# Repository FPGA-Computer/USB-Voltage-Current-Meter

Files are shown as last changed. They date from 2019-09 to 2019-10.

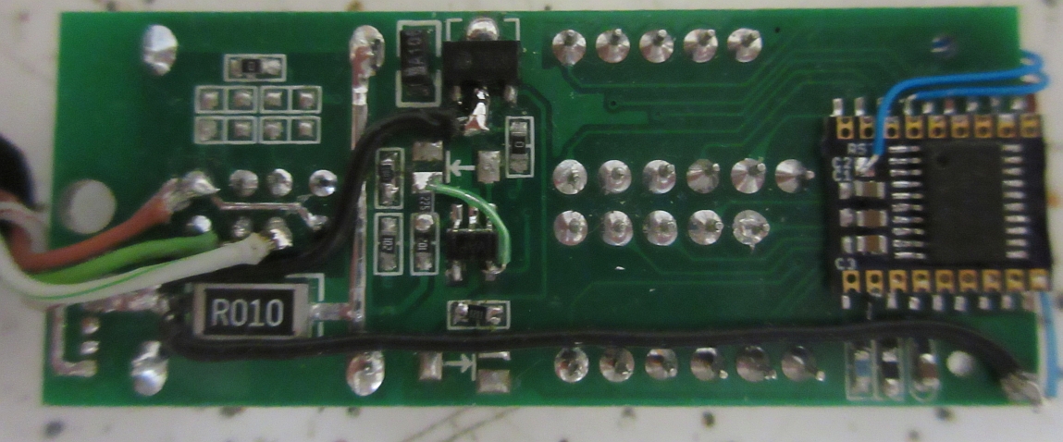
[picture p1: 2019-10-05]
hardware/uC Mod - PCB.JPG

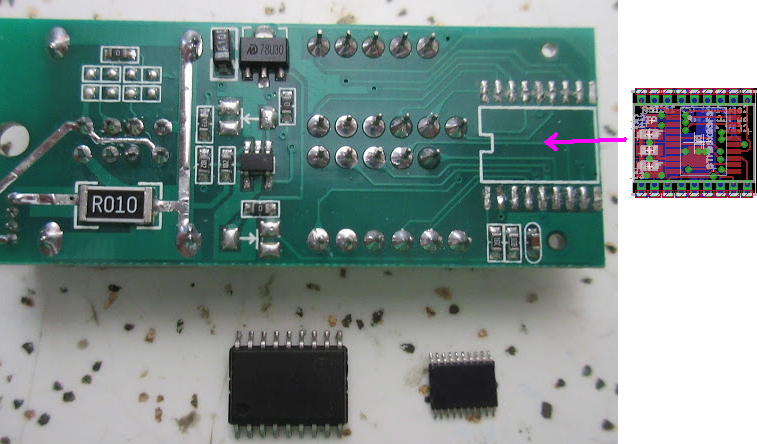
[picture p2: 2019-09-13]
hardware/PCB.png

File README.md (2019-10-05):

USB Meter
=========

This is the repository for my KW203 USB meter mod.
This mod is provided as is. This is a mod, so no full schematics.

The KW203 USB meter like most of those in the price range have very lousy
resolution and cannot read low currents.  This mod is replacing the
unknown microcontroller with a STM8S003F3 and a few modification to 
improve on the resolution and accuracy. The modifications and the 
calibration is what makes this a usable test equipment.

This is a hack that depends on the existing questionable components i.e. 
3V LDO (+/-3%) and current sensing resistor (??? %). 

Each unit has to be calibrated against a multimeter with a linear 
regression for reasonable accuracy. The current measurement suffers
from non-linearity at high current due to heating effects on the sense 
resistor and the bad layout traces. Trimppot won't help here.  To manage 
the errors, I use a piecewise linear fit. 

Firmware is written for Cosmic C which ST arranged to have for free use 
with their STM8 chips.

Project page: mod, documentations, photos

https://hw-by-design.blogspot.com/2019/08/usb-meter-modding.html

https://hw-by-design.blogspot.com/2019/09/usb-meter-modding-part-2.html

https://hw-by-design.blogspot.com/2019/10/uc-mod-pcb-part-3.html

Licensing:

Schematic/PCB: Creative Commons 4.0 Attribution-ShareAlike 4.0 International

Firmware: source code: GPL v3

Updates:

New PCB for the adapter board - verified.

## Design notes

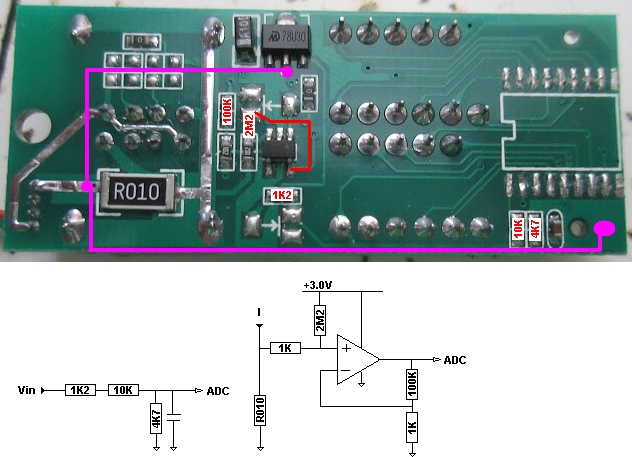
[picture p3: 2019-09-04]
hardware/Analog mod.jpg

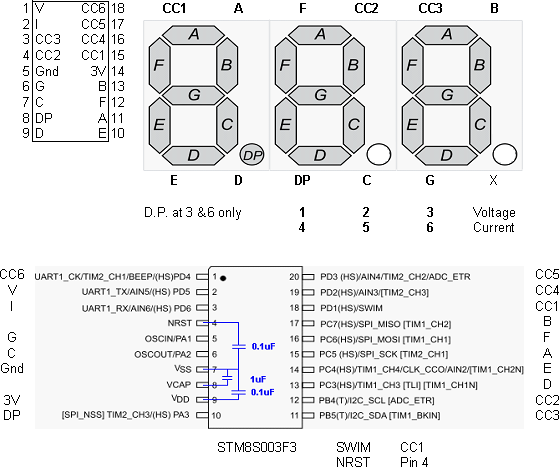
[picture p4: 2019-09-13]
hardware/uC pins mapping.png

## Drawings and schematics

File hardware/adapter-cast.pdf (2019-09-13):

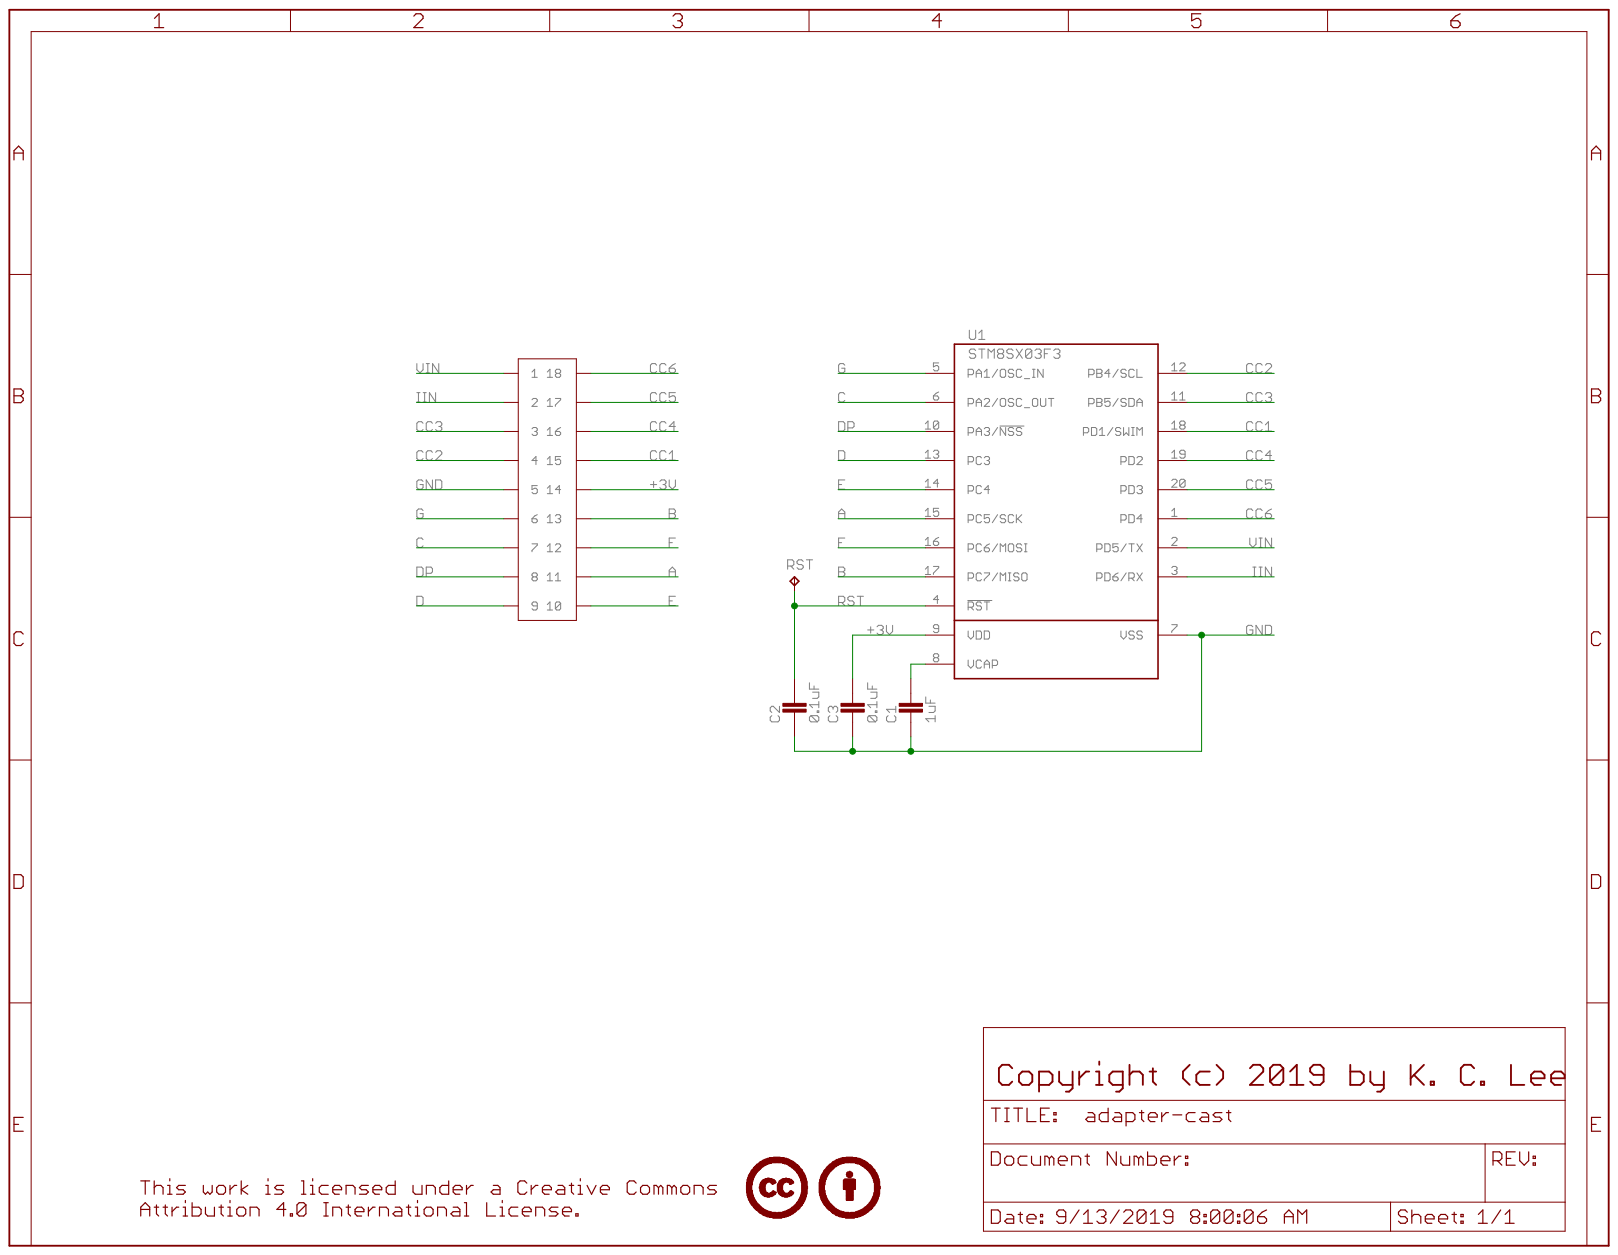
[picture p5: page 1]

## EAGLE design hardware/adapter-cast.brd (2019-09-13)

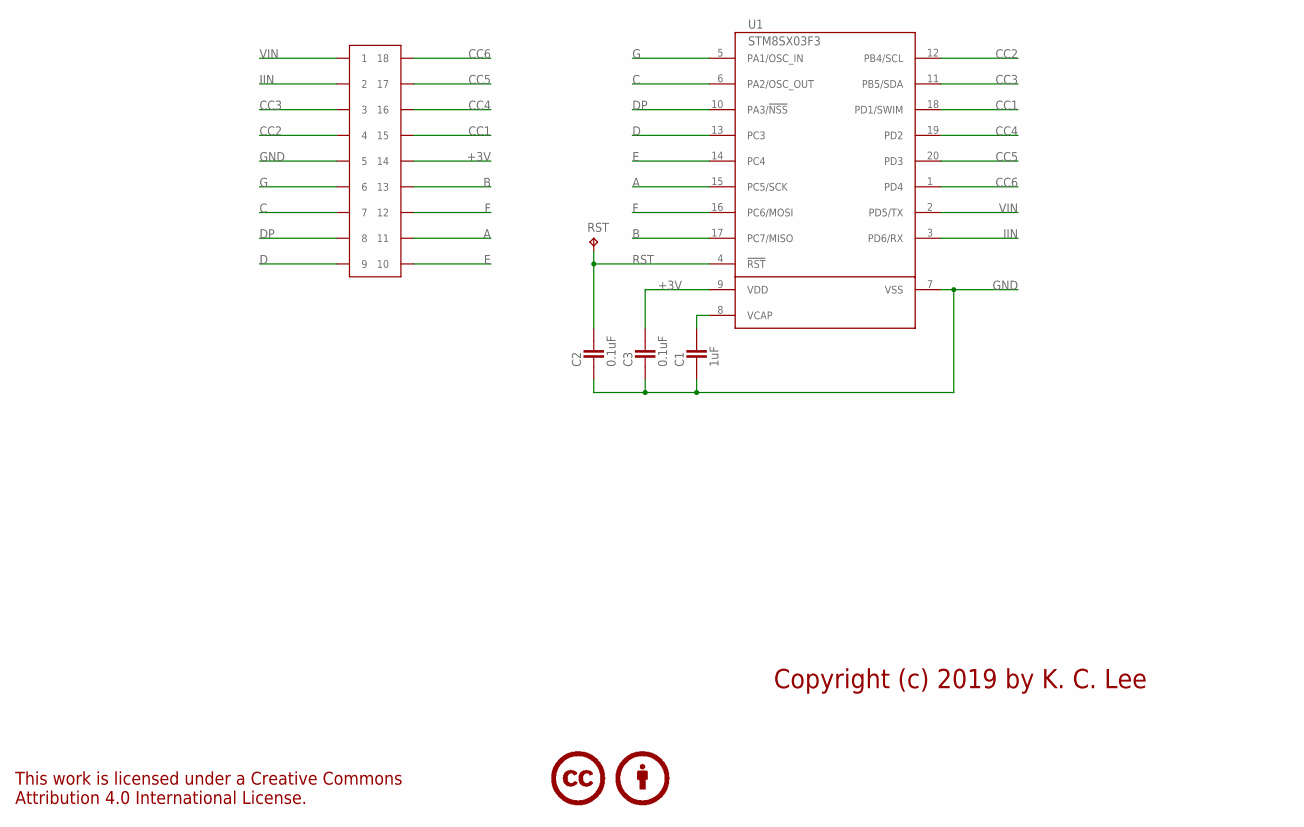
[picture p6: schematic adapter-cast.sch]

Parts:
C1: 1uF; CAPC1608X92N
C2, C3: 0.1uF; CAPC1608X92N
LICENSE1: CC-BYNONE; CC-NONE
P1: DUMMY-SO18WCAST; SO18W-CAST
RST: TP; TP11SQ
U1: STM8SX03F3; TSSOP20

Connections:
+3V: C3.2, P1.P$14 (14), U1.9 (VDD)
A: P1.P$11 (11), U1.15 (PC5/SCK)
B: P1.P$13 (13), U1.17 (PC7/MISO)
C: P1.P$7 (7), U1.6 (PA2/OSC_OUT)
CC1: P1.P$15 (15), U1.18 (PD1/SWIM)
CC2: P1.P$4 (4), U1.12 (PB4/SCL)
CC3: P1.P$3 (3), U1.11 (PB5/SDA)
CC4: P1.P$16 (16), U1.19 (PD2)
CC5: P1.P$17 (17), U1.20 (PD3)
CC6: P1.P$18 (18), U1.1 (PD4)
D: P1.P$9 (9), U1.13 (PC3)
DP: P1.P$8 (8), U1.10 (PA3/!NSS)
E: P1.P$10 (10), U1.14 (PC4)
F: P1.P$12 (12), U1.16 (PC6/MOSI)
G: P1.P$6 (6), U1.5 (PA1/OSC_IN)
GND: C1.1, C2.1, C3.1, P1.P$5 (5), U1.7 (VSS)
IIN: P1.P$2 (2), U1.3 (PD6/RX)
unnamed: C1.2, U1.8 (VCAP)
RST: C2.2, RST.TP, U1.4 (!RST)
VIN: P1.P$1 (1), U1.2 (PD5/TX)

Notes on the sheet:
Copyright (c) 2019 by K. C. Lee

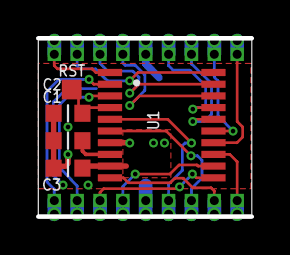
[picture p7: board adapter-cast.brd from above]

Board: 2 copper layers, 11.9 x 9.9 mm, 7 parts (0 on the bottom side), 20 nets.

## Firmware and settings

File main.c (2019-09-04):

/*
 * main.c
 *
 * Created: August 30, 2019, 6:07:55 PM
 *  Author: K. C. Lee
 * Copyright (c) 2017 by K. C. Lee
 
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
 If not, see http://www.gnu.org/licenses/gpl-3.0.en.html 
 */ 
 
#include "hardware.h"

void main(void)
{
	Init_Hardware();
	
	while(1)
	{
		wfi();		
		if(update)
		{
			update=0;
			Update();
		}
	}
}

void BinTo7Seg(int16_t Number,uint8_t Pos)
{
	uint8_t ZeroSup = Pos & ZERO_SUP;
	uint16_t Digit;
	
	Pos &= COL_MASK;
	
	if(Number<0)
	  Number = 0;
	
	Digit = Number/100;
	Number = Number%100;
	
	if(!Digit && ZeroSup)			// Supress 0
		Display[Pos++] = 0;
	else
	{	
		Display[Pos++] = CharMap[Digit];
		ZeroSup = 0;
	}
	
	Digit = Number/10;
	
	if(!Digit && ZeroSup)			// Supress 0
		Display[Pos++] = 0;
	else
		Display[Pos++] = CharMap[Digit];

	Digit = Number%10;
	Display[Pos] = CharMap[Digit];	
}

// For debug - display the raw value
void BinDisplay(int16_t Number)
{
	int16_t Digit;
	
	Digit = Number/10000;
	Number = Number%10000;
	Display[0] = 0;
	Display[1] = CharMap[Digit];
	Digit = Number/1000;
	Number = Number%1000;	
	Display[2] = CharMap[Digit];	
	BinTo7Seg(Number,3);
}

uint16_t Voltage[ADC_AVERAGES],Current[ADC_AVERAGES];
uint8_t SumIndex, flag;

void Update(void)
{	uint8_t i;
	int16_t V_Avg,I_Avg;
	
	V_Avg =ADC_Conv(VIN_CH);
	I_Avg = ADC_Conv(IIN_CH);

	// moving average
	Voltage[SumIndex] = ADC_Conv(VIN_CH);
	Current[SumIndex] = ADC_Conv(IIN_CH);

	if (++SumIndex >=ADC_AVERAGES)
	{
		SumIndex=0;
		flag = 1;
	}
	
	V_Avg = I_Avg = 0;
	
	for(i=0;i<ADC_AVERAGES;i++)
	{
		V_Avg += Voltage[i];
		I_Avg += Current[i];
	}

	V_Avg /= ADC_AVERAGES;
	I_Avg /= ADC_AVERAGES;

//#define CALIBRATE_I
//#define CALIBRATE_V
#ifdef CALIBRATE_I
	BinDisplay(I_Avg);
#else
#ifdef CALIBRATE_V
	BinDisplay(V_Avg);
#else

	// calibrated values - depends on parts
	V_Avg = (V_Avg*12200L)/48977L;
	
	// current requires piecewise fit.  Can divider it further to improve accuracy
	if(I_Avg<1014)	// 0.6A
		I_Avg = ((I_Avg-83)*1634000L)/2518955L;	
	else
		I_Avg = ((I_Avg-62)*86000L)/135423L;

	if(flag)
	{	
		Display[VOLTAGE_COL] = 0;
		
		if(V_Avg < VIN_LOW)
		{
			Display[VOLTAGE_COL+1] = CHAR_L;
			Display[VOLTAGE_COL+2] = CHAR_O;
		}
		else if(V_Avg >= VIN_HIGH)
		{ 
			Display[VOLTAGE_COL+1] = CHAR_O;
			Display[VOLTAGE_COL+2] = CHAR_V;
		}
		else if(V_Avg >= V_RANGE)
			BinTo7Seg(V_Avg/10,VOLTAGE_COL);
		else
		{
			BinTo7Seg(V_Avg,VOLTAGE_COL);
			Display[VOLTAGE_COL] |= SEG_DP;			// turn on decimal point
		}
		
		if(I_Avg < I_RANGE)
			BinTo7Seg(I_Avg,CURRENT_COL|ZERO_SUP);
		else
		{
			BinTo7Seg(I_Avg/10,CURRENT_COL);
			// turn on decimal point
			Display[CURRENT_COL] |= SEG_DP;		
		}
	}
#endif
#endif
}

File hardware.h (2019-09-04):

/*
 * hardware.h
 *
 * Created: August 30, 2019, 6:07:55 PM
 *  Author: K. C. Lee
 * Copyright (c) 2016 by K. C. Lee
 
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
 If not, see http://www.gnu.org/licenses/gpl-3.0.en.html 
 */ 

#ifndef HARDWARE_H_
#define HARDWARE_H_

#ifndef __CSMC__
#define __CSMC__
#endif
#define STM8S003

#include "stm8s.h"
#include <stdio.h>

// STM8S003F3P6
enum _PA { PA1=0x02, PA2=0x04, PA3=0x08 };
enum _PB { PB4=0x10, PB5=0x20 };
enum _PC { PC3=0x08, PC4=0x10, PC5=0x20, PC6=0x40, PC7=0x80 };
enum _PD { PD1=0x02, PD2=0x04, PD3=0x08, PD4=0x10, PD5=0x20, PD6=0x40 };

enum _IO7SEG
{ 
	IOSEG_G=PA1,IOSEG_C=PA2,IOSEG_DP=PA3,
	IOSEG_D=PC3,IOSEG_E=PC4,IOSEG_A=PC5,IOSEG_F=PC6,IOSEG_B=PC7
};

enum _7SEG_ENCODE
{
	SEG_G=IOSEG_G>>1,SEG_C=IOSEG_C>>1,SEG_DP=IOSEG_DP>>1,
	SEG_D=IOSEG_D,SEG_E=IOSEG_E,SEG_A=IOSEG_A,SEG_F=IOSEG_F,SEG_B=IOSEG_B
};

enum _CC_DRV
{ 
	CC2=PB4,CC2_PORT=GPIOB_BaseAddress,
	CC3=PB5,CC3_PORT=GPIOB_BaseAddress,
	CC1=PD1,CC1_PORT=GPIOD_BaseAddress,
	CC4=PD2,CC4_PORT=GPIOD_BaseAddress,
	CC5=PD3,CC5_PORT=GPIOD_BaseAddress,
	CC6=PD4,CC6_PORT=GPIOD_BaseAddress
};


#define PA_SEGS	(IOSEG_C|IOSEG_G|IOSEG_DP)
#define PB_COLS	(CC2|CC3)
#define PC_SEGS	(IOSEG_D|IOSEG_E|IOSEG_A|IOSEG_F|IOSEG_B)
#define PD_COLS	(CC1|CC4|CC5|CC6)

#define PORTA_SEG(X)		(((X) & (PA_SEGS>>1))<<1)
#define PORTC_SEG(X)		((X) & PC_SEGS)

#define GPIO_ODR(X)			((GPIO_TypeDef *)(X))->ODR

#define COLUMN_MAX			6

#define VOLTAGE_COL			0
#define CURRENT_COL			3

typedef struct 
{
	uint8_t		Bit;
	uint16_t	Port;
} Column_Drv_t;

#include "irq.h"

#define CPU_CLK					2000000UL

// 16MHz/4096 -> 3906Hz
#define TIM2_PSCR				0x0c
// reload for 355Hz/6 columns -> 59Hz
#define TIM2_ARRH				0x00
#define TIM2_ARRL				0x0a
// update every 12 display refresh
#define TICK_MAX				(COLUMN_MAX*12-1)

// ADC clock div = 1/8
#define ADC_CLKDIV			0x20

#define ADC_OVERSAMPLE	16
#define ADC_DECIMATE		4

#define ADC_AVERAGES		4

#define VIN_CH					5
#define IIN_CH					6

#define CHAR_O					(SEG_A|SEG_B|SEG_C|SEG_D|SEG_E|SEG_F)
#define CHAR_L					(SEG_D|SEG_E|SEG_F)
#define CHAR_V					(SEG_B|SEG_C|SEG_D|SEG_E|SEG_F)

#define ZERO_SUP				0x80
#define COL_MASK				0x0f

#define VIN_LOW					319
#define VIN_HIGH				1019
#define V_RANGE					1000
#define I_RANGE					1000

extern volatile uint8_t tick,update;
extern volatile uint8_t Display[];
extern const uint8_t CharMap[];

void Init_Hardware(void);
void Update(void);
uint16_t ADC_Conv(uint8_t Ch);

#endif

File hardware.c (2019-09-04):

/*
 * hardware.c
 *
 * Created: August 30, 2019, 6:35:08 PM
 *  Author: K. C. Lee
 * Copyright (c) 2016 by K. C. Lee
 
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
 If not, see http://www.gnu.org/licenses/gpl-3.0.en.html 
 */ 

#include "hardware.h"

volatile uint8_t Display_Col,tick,update;
volatile uint8_t Display[COLUMN_MAX];

const uint8_t CharMap[] =
{
/* 7 segment display

     --- A ---
    |         |
    F         B
    |         |
     --- G ---
    |         |
    E         C
    |         |
     --- D ---  DP
*/

	/* 0 */	SEG_A|SEG_B|SEG_C|SEG_D|SEG_E|SEG_F,
	/* 1 */	      SEG_B|SEG_C,
	/* 2 */	SEG_A|SEG_B|      SEG_D|SEG_E|      SEG_G,
	/* 3 */	SEG_A|SEG_B|SEG_C|SEG_D|            SEG_G,
	/* 4 */	      SEG_B|SEG_C|            SEG_F|SEG_G,
	/* 5 */	SEG_A|      SEG_C|SEG_D|      SEG_F|SEG_G,
	/* 6 */	SEG_A|      SEG_C|SEG_D|SEG_E|SEG_F|SEG_G,
	/* 7 */	SEG_A|SEG_B|SEG_C,
	/* 8 */ SEG_A|SEG_B|SEG_C|SEG_D|SEG_E|SEG_F|SEG_G,
	/* 9 */	SEG_A|SEG_B|SEG_C|SEG_D|      SEG_F|SEG_G,
};

const Column_Drv_t ColumnDrv[] = 
{	
	{	~CC1,CC1_PORT }, 
	{	~CC2,CC2_PORT },
	{ ~CC3,CC3_PORT },
	{	~CC4,CC4_PORT },
	{	~CC5,CC5_PORT },
	{	~CC6,CC6_PORT },
};

void Init_Hardware(void)
{
	// Clk = 16MHz
	CLK->CKDIVR = 0;
	
	// turn on ADC, clock = /8
	ADC1->CR1 = ADC_CLKDIV|ADC1_CR1_ADON;
	// ADC data is right align
	ADC1->CR2 = ADC1_CR2_ALIGN;
	
	Display_Col =0;
	
	// 7 seg drivers = push/pull
	GPIOA->DDR = GPIOA->CR1 = PA_SEGS;
	GPIOC->DDR = GPIOC->CR1 = PC_SEGS;
	
	// column drivers = open drain, set to '1'
	GPIOB->DDR = GPIOB->ODR = PB_COLS;	
	GPIOD->DDR = GPIOD->ODR = PD_COLS;
	
	TIM2->PSCR = TIM2_PSCR;
	TIM2->ARRH = TIM2_ARRH;
	TIM2->ARRL = TIM2_ARRL;
	
		// TIM2 enable
	TIM2->CR1 = TIM2_CR1_CEN;
	// Update interrupt
	TIM2->IER = TIM2_IER_UIE;
	
	update=0;
	
		// Turn on interrupts
	rim();
}

uint16_t ADC_Conv(uint8_t Ch)
{
	uint8_t i;
	uint16_t ADC_Sum;
	
	// select ADC channel
	ADC1->CSR = Ch;
	ADC_Sum=0;
	
	for(i=ADC_OVERSAMPLE;i;i--)
	{
		// clear EOC flag
		ADC1->CSR &= ~ADC1_CSR_EOC;
		// start ADC, clock = /8
		ADC1->CR1 = ADC_CLKDIV|ADC1_CR1_ADON;

		while(!(ADC1->CSR & ADC1_CSR_EOC))
		  /* wait */;
		
		// read 16-bit value L->H
		ADC_Sum += *((uint16_t*)&ADC1->DRH);
	}
	return(ADC_Sum/ADC_DECIMATE);
}

@far @interrupt void TIM2_Update_IRQ(void)
{
	TIM2->SR1 &= ~TIM2_SR1_UIF;
	// clear display
	GPIOB->ODR = PB_COLS;	
	GPIOD->ODR = PD_COLS;
	
	if(Display_Col>=COLUMN_MAX)
	  Display_Col=0;
	else
		Display_Col++;	

	// Turn on column
	GPIO_ODR(ColumnDrv[Display_Col].Port) = ColumnDrv[Display_Col].Bit;
	
	// Turn on segments
	GPIOA->ODR = PORTA_SEG(Display[Display_Col]);
	GPIOC->ODR = PORTC_SEG(Display[Display_Col]);
	
	if(tick)
		tick--;
	else
	{
		tick = TICK_MAX;
		update = 1;
	}
}

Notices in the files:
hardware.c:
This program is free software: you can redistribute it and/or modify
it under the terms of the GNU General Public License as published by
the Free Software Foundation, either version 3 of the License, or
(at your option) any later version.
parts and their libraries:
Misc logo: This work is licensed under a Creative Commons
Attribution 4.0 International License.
